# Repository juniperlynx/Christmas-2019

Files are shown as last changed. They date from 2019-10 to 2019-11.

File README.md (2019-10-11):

# 2019 Christmas Cards

Software and board layouts for my 2019 Christmas cards. These use an AtTiny84 to drive a 4x5 Charlieplexed LED array to display messages and run on a CR2032 coin cell. A cutout is included to hang them up.

Board design, software, and logo graphics by Juniper Starr and licensed CC BY 4.0. Graphics made with the Snowtop Caps font are property of [Deiter Steffmann](http://www.steffmann.de) and are free for noncommercial use only.

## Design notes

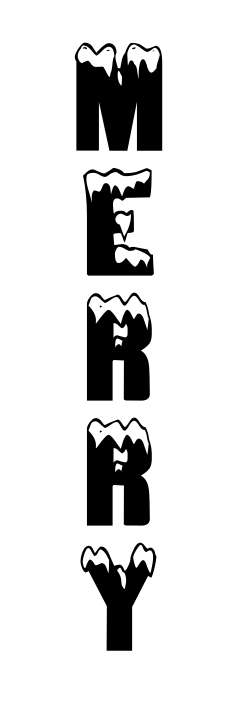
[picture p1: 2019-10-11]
Graphics/Merry.png

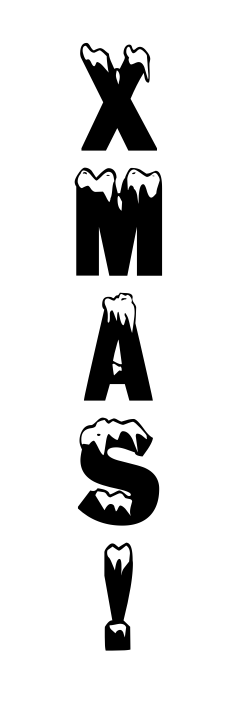
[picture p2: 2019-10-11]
Graphics/Xmas.png

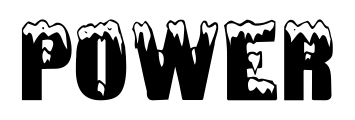
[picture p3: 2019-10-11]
Graphics/Power.png

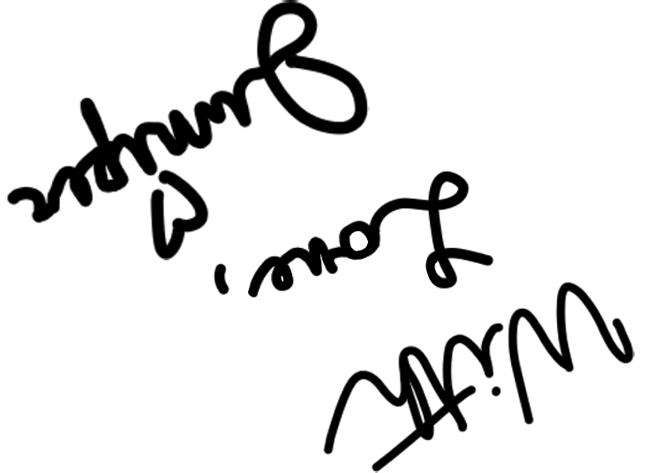
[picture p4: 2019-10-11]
Graphics/Signature.png

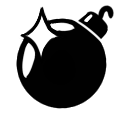
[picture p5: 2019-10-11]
Graphics/Bauble.png

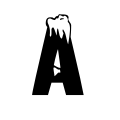
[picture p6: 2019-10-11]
Graphics/A.png

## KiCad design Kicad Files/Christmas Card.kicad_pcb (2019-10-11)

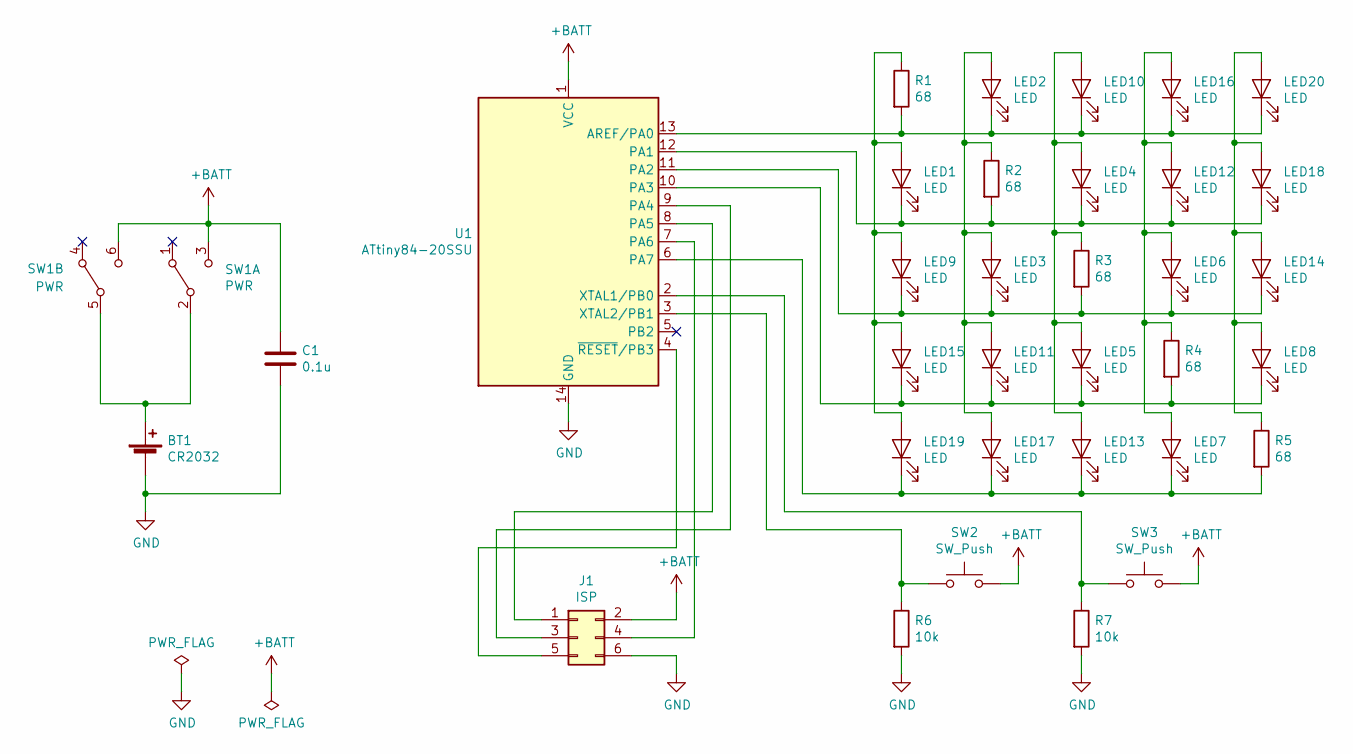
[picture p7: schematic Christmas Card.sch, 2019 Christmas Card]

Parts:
BT1: CR2032; BatteryStrap BC-2003-G-TR
C1: 0.1u; C_0805_2012Metric
J1: ISP; PinHeader_2x03_P2.54mm_Vertical
LED1, LED2, LED3, LED4, LED5, LED6, LED7, LED8, LED9, LED10, LED11, LED12, LED13, LED14, LED15, LED16, LED17, LED18, LED19, LED20: LED; LED_0805_2012Metric
R1, R2, R3, R4, R5: 68; R_0805_2012Metric
R6, R7: 10k; R_0805_2012Metric
SW1: PWR; SlideSwitch JS202011SQCN
SW2, SW3: SW_Push; SW_SPST_PTS645
U1: ATtiny84-20SSU; SOIC-14_3.9x8.7mm_P1.27mm

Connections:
+BATT: C1.1, J1.2, SW1.3 (C), SW1.6 (C), SW2.2, SW3.2, U1.1 (VCC); also elsewhere on the board
GND: BT1.2 (-), C1.2, J1.6, R6.2, R7.2, U1.14 (GND); also elsewhere on the board
unnamed: BT1.1 (+), SW1.2 (B), SW1.5 (B)
unnamed 3: J1.1, U1.8 (PA5); also elsewhere on the board
unnamed 4: J1.3, U1.9 (PA4); also elsewhere on the board
unnamed 5: J1.4, U1.7 (PA6); also elsewhere on the board
unnamed 6: J1.5, U1.4 (~RESET~/PB3); also elsewhere on the board
unnamed 7: LED1.1 (K), LED4.1 (K), LED12.1 (K), LED18.1 (K), R2.2, U1.12 (PA1); also elsewhere on the board
unnamed: LED1.2 (A), LED9.2 (A), LED15.2 (A), LED19.2 (A), R1.1
unnamed 9: LED2.1 (K), LED10.1 (K), LED16.1 (K), LED20.1 (K), R1.2, U1.13 (AREF/PA0); also elsewhere on the board
unnamed: LED4.2 (A), LED5.2 (A), LED10.2 (A), LED13.2 (A), R3.1
unnamed 11: LED5.1 (K), LED8.1 (K), LED11.1 (K), LED15.1 (K), R4.2, U1.10 (PA3); also elsewhere on the board
unnamed 12: LED2.2 (A), LED3.2 (A), LED11.2 (A), LED17.2 (A), R2.1; also elsewhere on the board
unnamed 13: LED6.2 (A), LED7.2 (A), LED12.2 (A), LED16.2 (A), R4.1; also elsewhere on the board
unnamed 14: LED7.1 (K), LED13.1 (K), LED17.1 (K), LED19.1 (K), R5.2, U1.6 (PA7); also elsewhere on the board
unnamed 15: LED3.1 (K), LED6.1 (K), LED9.1 (K), LED14.1 (K), R3.2, U1.11 (PA2); also elsewhere on the board
unnamed: LED8.2 (A), LED14.2 (A), LED18.2 (A), LED20.2 (A), R5.1
unnamed 17: R6.1, SW2.1, U1.3 (XTAL2/PB1); also elsewhere on the board
unnamed 18: R7.1, SW3.1, U1.2 (XTAL1/PB0); also elsewhere on the board

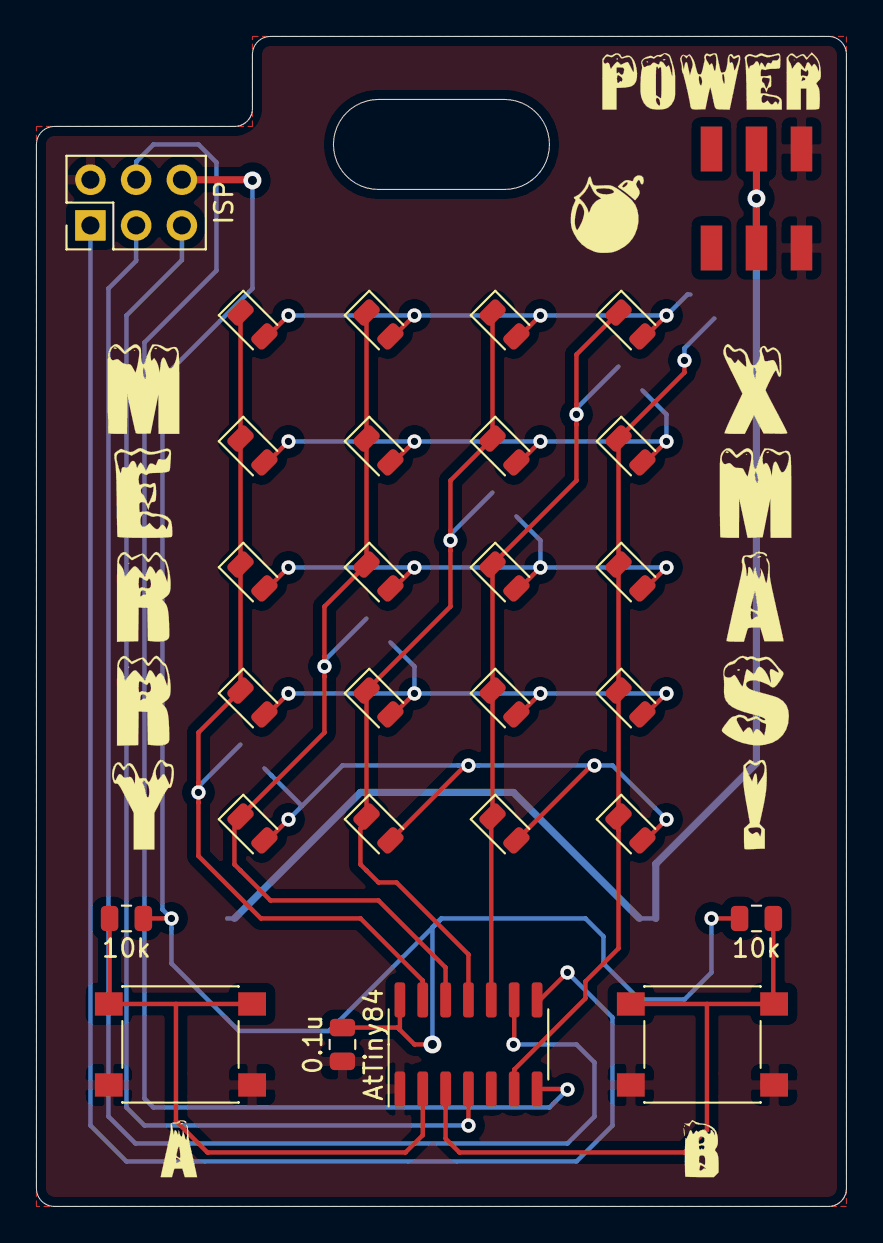
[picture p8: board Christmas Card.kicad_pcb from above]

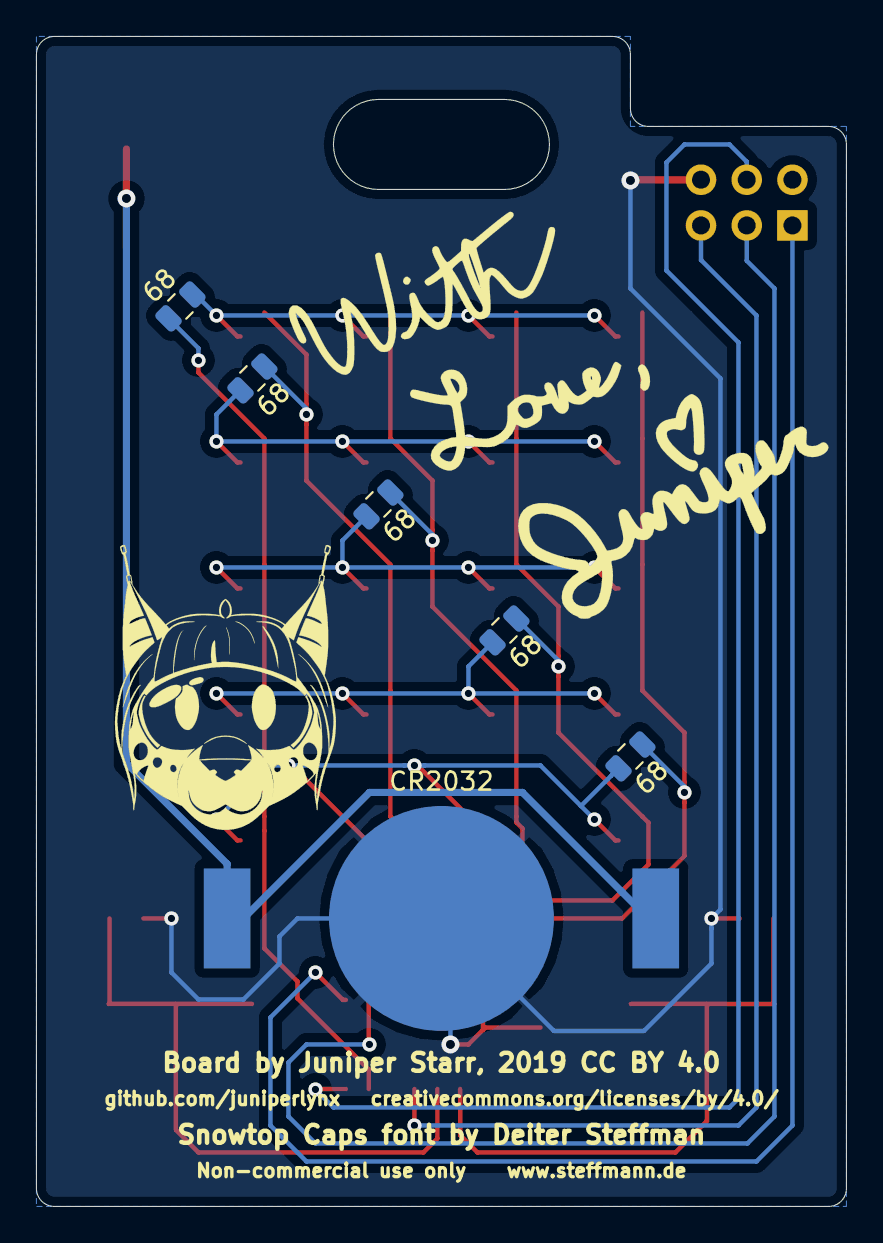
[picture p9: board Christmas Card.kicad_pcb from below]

Board: 2 copper layers, 45.0 x 65.0 mm, 34 parts (6 on the bottom side), 19 nets.

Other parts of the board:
AtTiny84: ATtiny84-20SSU; SOIC-14_3.9x8.7mm_P1.27mm
LED: LED; LED_0805_2012Metric
LED#2: LED; LED_0805_2012Metric

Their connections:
+BATT: AtTiny84.1; also elsewhere on the board
GND: AtTiny84.14; also elsewhere on the board
unnamed 3: AtTiny84.8; also elsewhere on the board
unnamed 4: AtTiny84.9; also elsewhere on the board
unnamed 5: AtTiny84.7; also elsewhere on the board
unnamed 6: AtTiny84.4; also elsewhere on the board
unnamed 7: AtTiny84.12; also elsewhere on the board
unnamed 9: AtTiny84.13; also elsewhere on the board
unnamed 11: AtTiny84.10; also elsewhere on the board
unnamed 12: LED.2; also elsewhere on the board
unnamed 13: LED#2.2; also elsewhere on the board
unnamed 14: AtTiny84.6; also elsewhere on the board
unnamed 15: AtTiny84.11, LED.1, LED#2.1; also elsewhere on the board
unnamed 17: AtTiny84.3; also elsewhere on the board
unnamed 18: AtTiny84.2; also elsewhere on the board

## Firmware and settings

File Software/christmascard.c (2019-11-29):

// Firmware for a Christmas card with a Charlieplexed display
// By:   _           _               
//      (_)_  _ _ _ (_)_ __  ___ _ _ 
//      | | || | ' \| | '_ \/ -_) '_|
//     _/ |\_,_|_||_|_| .__/\___|_|  
//    |__/            |_|  
// Filename: christmascard.c
// Date: Nov 23, 2019

// Define CPU frequency for delay function (must be before delay.h include)
#define F_CPU 800000UL

// Include AVR I/O defines, the delay function, and a 3x5 font
#include <avr/io.h>
#include <avr/interrupt.h>
#include <util/delay.h>
#include <string.h>
#include <stdlib.h>
#include "christmasdisplay.h"

// Sets constants for animations
#define GREETING_STRING " Hello World!"
#define GREETING_DELAY 175
#define SNOW_PROB 15
#define SNOW_DELAY 225

// Define possible modes
#define SCROLL_MODE 1
#define SNOW_MODE 2

// Declare variable to hold current mode
volatile uint8_t mode = SCROLL_MODE;

// Declare variable to hold surrent phase of screen update
volatile uint8_t phase = 0;

// Declare screen VRAM, least significant 5 bits are columns of screen
uint8_t display[NUM_COLS] = {0x00, 0x00, 0x00, 0x00};

// Sets up DDR, Prescaler, and interrupts
void christmasInit(void) {
    // Set DDRA as input (for now) and DDRB0 & 1 as input
    DDRA = 0;
    DDRB &= ~(_BV(DDB0) | _BV(DDB1));

    // Initialize Timer1
    cli();         // Disable global interrupts
    TCCR1A = 0;    // Clear TCCR1A
    TCCR1B = 0;    // Clear TCCR1B

    // Set prescaler to 1 and WGM 13:10 to 0100 (CTC)
    TCCR1B |= _BV(CS10) | _BV(WGM12);

    // Set output compare register to 1023 (1024 cycles)
    OCR1A = 1023;

    // Enable Timer1 output compare interrupts
    TIMSK1 |= _BV(OCIE1A);

    // Enable global interrupts
    sei();

    // Disable ADC before shutdown
    ADCSRA &= ~_BV(ADEN);

    // Shutdown ADC and USI for power savings
    PRR |= _BV(PRADC) | _BV(PRUSI);
}

// Scrolls the greeting on the display
void scrollChars(const char* greeting) {
    // Declare indexes and buffers
    char scrollbuffer[NUM_COLS * 2];
    uint8_t slice;
    uint8_t strindex;
    uint8_t column;

    // Iterate across string
    for (strindex = 0; strindex < strlen(greeting); strindex++) {
        // Fill scroll buffer with appropriate data for this char
        for (column = 0; column < NUM_COLS; column++) {
            scrollbuffer[column] = getFontCol(greeting[strindex], column);
        }

        // If at the end of the string, fill second char from beginning of greeting
        if (strindex + 1 >= strlen(greeting)) {
            for (column = 0; column < NUM_COLS; column++) {
                scrollbuffer[column + NUM_COLS] = getFontCol(greeting[0], column);
            }
        }
        // Otherwise fill second char from next char
        else {
            for (column = 0; column < NUM_COLS; column++) {
                scrollbuffer[column + NUM_COLS] = getFontCol(greeting[strindex + 1], column);
            }
        }

        // Iterate through each slice of scroll
        for (slice = 0; slice < NUM_COLS; slice++) {
            // Copy each column for this slice
            for (column = 0; column < NUM_COLS; column++) {
                display[column] = scrollbuffer[slice + column];
            }
            // Delay after each slice
            _delay_ms(GREETING_DELAY);
        }
    }
}

// Runs a crude falling snow animation
void animateSnow() {
    // Declare index
    uint8_t column;

    // iterate across each column
    for (column = 0; column < NUM_COLS; column++) {
       // If set the top bit 15% of the time
       if (rand() % 100 < SNOW_PROB) {
           display[column] |= 1 << (NUM_ROWS + 1);
       }
       // Shift all bits down (snow's gotta fall)
       display[column] = display[column] >> 1;
    }

    // Delay after each frame
    _delay_ms(SNOW_DELAY);
}

// Timer0 ISR
ISR(TIM1_COMPA_vect) {
    // Display current bit
    displayBit(phase, display);

    // Increment phase, loop if NUM_LEDS exceeded
    phase++;
    if (phase >= NUM_LEDS) {
        phase = 0;
    }

    // If "A" pressed, but not "B", switch to scroll mode
    if ((PINB & _BV(PB0)) && !(PINB & _BV(PB1))) {
        mode = SCROLL_MODE;
    }
    // If "B" pressed, switch to snow mode
    if ((PINB & _BV(PB1)) && !(PINB & _BV(PB0))) {
        mode = SNOW_MODE;
    }
}

int main(void) {
    const char greeting[] = GREETING_STRING;

    // Setup DDRs, interrupts, &c
    christmasInit();

    // Cycle modes, Wait for interrupts
    while(1) {
        switch (mode) {
            case SCROLL_MODE :
                scrollChars(greeting);
                break;
            case SNOW_MODE :
                animateSnow();
                break;
       }
    }
}

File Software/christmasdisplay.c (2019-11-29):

// Display function file for a Christmas card with a Charlieplexed display
// By:   _           _               
//      (_)_  _ _ _ (_)_ __  ___ _ _ 
//      | | || | ' \| | '_ \/ -_) '_|
//     _/ |\_,_|_||_|_| .__/\___|_|  
//    |__/            |_|  
// Filename: christmasdisplay.c
// Date: Nov 28, 2019

// Include AVR I/O defines, the delay function, and a 3x5 font
#include <avr/io.h>
#include "christmasdisplay.h"
#include "christmasfont.h"

// Lights an individual LED as specified. Expects PORTA and DDRA to be cleared first.
// I know this is uncreative, but eh...
// Physically mapped as follows:
//     4  9  14 19
//     3  8  13 18
//     2  7  12 17
//     1  6  11 16
//     0  5  10 15
void lightLED(uint8_t led) {
    // Set needed bits
    switch (led) {
        case 0 :
            DDRA |= _BV(PA0) | _BV(PA1);
            PORTA |= _BV(PA0);
            break;
        case 1 :
            DDRA |= _BV(PA0) | _BV(PA1);
            PORTA |= _BV(PA1);
            break;
        case 2 :
            DDRA |= _BV(PA0) | _BV(PA2);
            PORTA |= _BV(PA2);
            break;
        case 3 :
            DDRA |= _BV(PA0) | _BV(PA3);
            PORTA |= _BV(PA3);
            break;
        case 4 :
            DDRA |= _BV(PA0) | _BV(PA7);
            PORTA |= _BV(PA7);
            break;
        case 5 :
            DDRA |= _BV(PA0) | _BV(PA2);
            PORTA |= _BV(PA0);
            break;
        case 6 :
            DDRA |= _BV(PA1) | _BV(PA2);
            PORTA |= _BV(PA1);
            break;
        case 7 :
            DDRA |= _BV(PA1) | _BV(PA2);
            PORTA |= _BV(PA2);
            break;
        case 8 :
            DDRA |= _BV(PA1) | _BV(PA3);
            PORTA |= _BV(PA3);
            break;
        case 9 :
            DDRA |= _BV(PA1) | _BV(PA7);
            PORTA |= _BV(PA7);
            break;
        case 10 :
            DDRA |= _BV(PA0) | _BV(PA3);
            PORTA |= _BV(PA0);
            break;
        case 11 :
            DDRA |= _BV(PA1) | _BV(PA3);
            PORTA |= _BV(PA1);
            break;
        case 12 :
            DDRA |= _BV(PA2) | _BV(PA3);
            PORTA |= _BV(PA2);
            break;
        case 13 :
            DDRA |= _BV(PA2) | _BV(PA3);
            PORTA |= _BV(PA3);
            break;
        case 14 :
            DDRA |= _BV(PA2) | _BV(PA7);
            PORTA |= _BV(PA7);
            break;
        case 15 :
            DDRA |= _BV(PA0) | _BV(PA7);
            PORTA |= _BV(PA0);
            break;
        case 16 :
            DDRA |= _BV(PA1) | _BV(PA7);
            PORTA |= _BV(PA1);
            break;
        case 17 :
            DDRA |= _BV(PA2) | _BV(PA7);
            PORTA |= _BV(PA2);
            break;
        case 18 :
            DDRA |= _BV(PA3) | _BV(PA7);
            PORTA |= _BV(PA3);
            break;
        case 19 :
            DDRA |= _BV(PA3) | _BV(PA7);
            PORTA |= _BV(PA7);
            break;
    }
}

// Displays a bit corresponding to the current phase of the display update
// if the corresponding bit of the diaplay array is set.
void displayBit(uint8_t phase, uint8_t display[NUM_COLS]) {
    // Clear DDRA and PORTA
    DDRA = 0;
    PORTA = 0;

    // Light current phase's LED if a one is present in the corresponding bit
    if (display[phase / NUM_ROWS] >> (phase % NUM_ROWS) & 0x01) {
        lightLED(phase);
    }
}

// Wrapper to grab characters from the font function by column 
uint8_t getFontCol(char character, uint8_t column) {
    // If asking for anything beyond the third column, return zero
    if (column >= NUM_COLS - 1) {
        return 0x00;
    }
    // If asking for non printable characters, return zero
    else if ((int)character < 32 || (int)character > 126) {
        return 0x00;
    }
    // Otherwise, return the correct entry from the font variable in christmasfont.h
    else {
        return font[(int)character - 32][column];
    }
}

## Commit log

2019-11-25 Initial Software
    [Christmas Card.sch]
2019-11-29 Add snow animation and mode switching

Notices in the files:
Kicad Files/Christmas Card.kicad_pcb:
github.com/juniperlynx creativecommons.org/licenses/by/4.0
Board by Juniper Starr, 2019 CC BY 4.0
